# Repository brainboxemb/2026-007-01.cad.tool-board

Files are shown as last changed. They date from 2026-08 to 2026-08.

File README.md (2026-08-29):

# Garage Layout

Parametric OpenSCAD model used as visual support while making layout and construction choices for a private garage / workshop.

> The model and documentation were developed with the assistance of ChatGPT.

## Visual concept

Two visual concept renders are used to explore the intended appearance of the rear-wall tool-board layout. These images are illustrative rather than dimensional; the OpenSCAD model remains the geometric reference.

### Concept — straight view

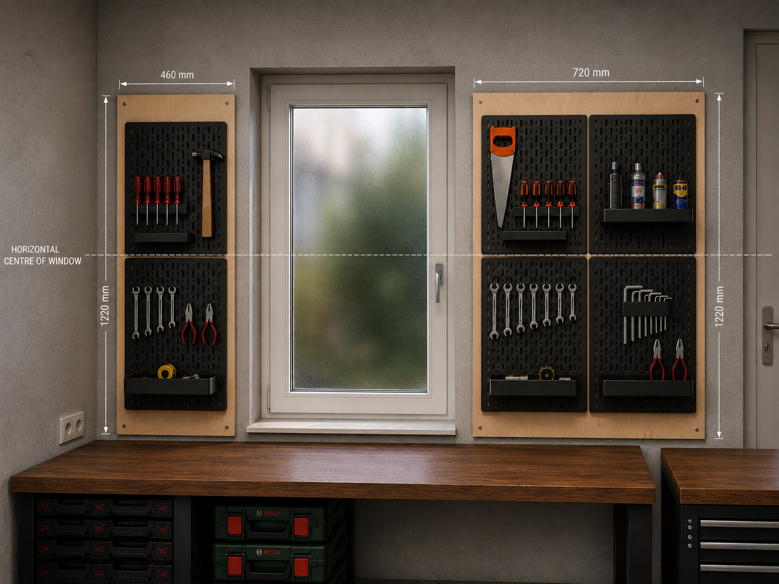
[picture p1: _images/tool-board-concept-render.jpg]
Tool-board concept render — straight


### Concept — angled view

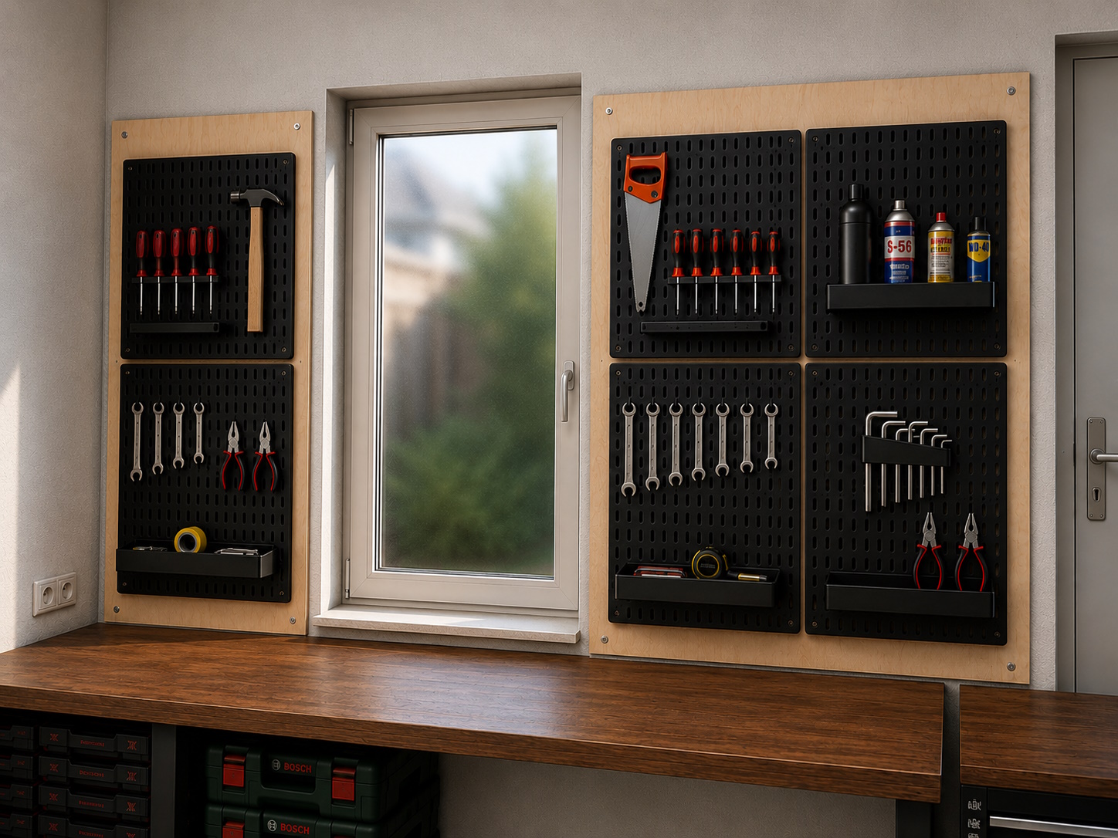
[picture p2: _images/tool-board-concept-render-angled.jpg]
Tool-board concept render — angled


### OpenSCAD implementation — straight view

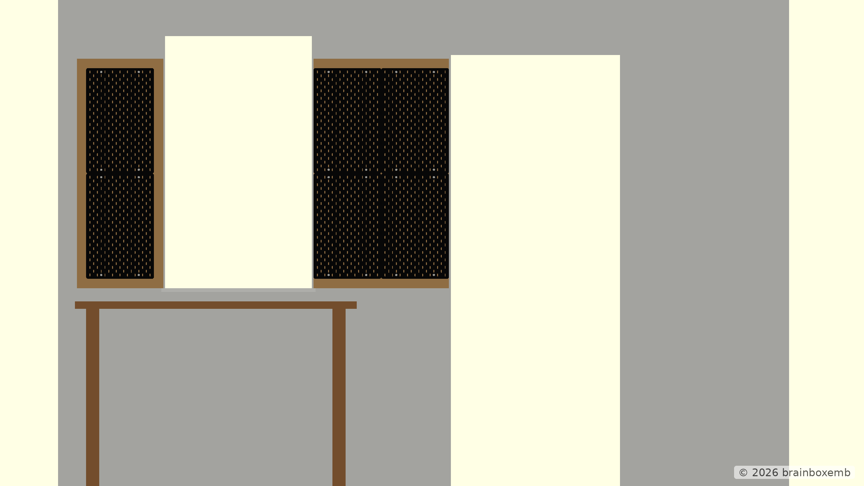
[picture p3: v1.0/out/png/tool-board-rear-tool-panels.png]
OpenSCAD rear tool-board implementation — straight


### OpenSCAD implementation — angled view

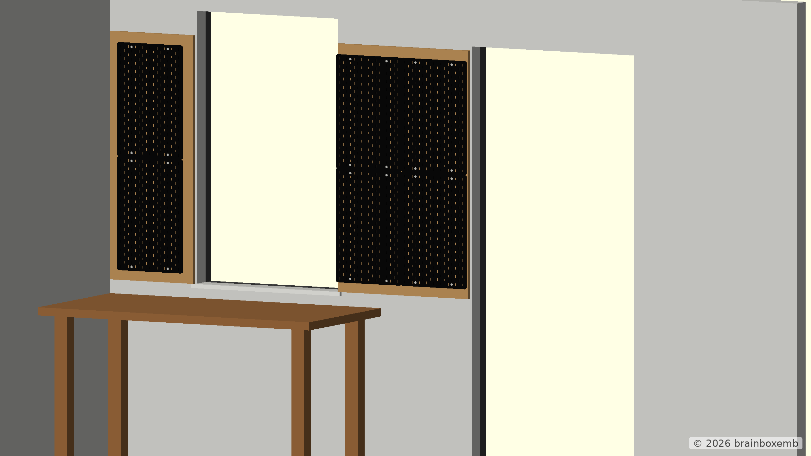
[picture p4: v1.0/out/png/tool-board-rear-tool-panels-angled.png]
OpenSCAD rear tool-board implementation — angled


The concept renders help evaluate visual balance and overall appearance, while the OpenSCAD views are used to check dimensions, alignment and spatial relationships.

For the reference-grid view and additional model notes, see [`v1.0/doc/design-overview.md`](v1.0/doc/design-overview.md).
## Project status

This is primarily a **private design and exploration project**, not an attempt to create a complete architectural or photorealistic garage model.

The main goal is to investigate how OpenSCAD can support practical home and workshop design decisions. The model is used to place real dimensions in context, compare alternatives, check proportions and visualize mounting concepts before buying materials or building anything.

Accuracy is therefore focused on the dimensions and details that affect a decision. Other geometry may deliberately remain simplified.

The current model concentrates on the **rear wall of the garage** and the first wall-storage concept around the existing window, door and workbench.

## Visual design overview

An extended visual overview of the current v1.0 model, including the generated OpenSCAD renders and short notes per view, is available here:

- [v1.0 design overview](v1.0/doc/design-overview.md)

## Rear-wall dimensions

| Item | Dimension |
| --- | ---: |
| Rear wall width | 3800 mm |
| Garage height | 2600 mm |
| Modelled concrete wall thickness | 90 mm |
| Current modelled left-wall depth | 2000 mm (temporary) |
| Window opening | 780 × 1340 mm |
| Window offset from left wall | 480 mm |
| Space above window | 200 mm |
| Door height | 2300 mm |
| Workbench | 1500 × 750 × 990 mm |
| Left backing panel | 460 × 1220 × 18 mm |
| Right backing panel | 720 × 1220 × 18 mm |
| SKÅDIS panel | 360 × 560 mm |

Current SKÅDIS arrangement:

- **left:** 1 × 2 panels;
- **right:** 2 × 2 panels.

## Backing-panel material

The SKÅDIS panels will not be mounted directly to the concrete. A wooden backing panel provides a cleaner mounting surface and makes later changes or additional workshop attachments easier.

Two practical sheet materials were considered.

### 18 mm pine plywood — preferred

The current design uses **18 mm pine plywood**.

Example material:

- GAMMA — Multiplex grenen 244 × 122 cm, 18 mm  
  <https://www.gamma.nl/assortiment/multiplex-grenen-244x122cm-dikte-18mm/p/B368216>

Reasons for preferring plywood:

- cleaner visible finish than OSB;
- good screw holding for SKÅDIS rails and later additions;
- easier to machine accurately for the recessed hanging hardware;
- edges can be finished neatly;
- more appropriate for a visible workshop wall that may evolve over time.

### 18 mm OSB3 — alternative

OSB3 was considered as the lower-cost alternative.

Example material:

- GAMMA — OSB3 244 × 122 cm, 18 mm  
  <https://www.gamma.nl/assortiment/osb3-plaat-244-x-122-cm-18-mm-rechte-kanten/p/B112332>

OSB is structurally suitable for this concept, but the rougher appearance, edges and less refined machining make plywood the preferred option here.

### Cutting concept

The required backing panels are:

- **460 × 1220 × 18 mm** — left;
- **720 × 1220 × 18 mm** — right.

Together they require 1180 mm of the 1220 mm sheet width, so both can be cut from a **single 2440 × 1220 mm sheet** with useful material remaining for tests, spacers or other workshop parts.

## SKÅDIS mounting

The intended pegboards are black IKEA SKÅDIS panels in the standard **36 × 56 cm** orientation.

Product reference:

- IKEA SKÅDIS pegboard 36 × 56 cm  
  <https://www.ikea.com/nl/nl/p/skadis-pegboard-zwart-80534372/>

The SKÅDIS boards are mounted to the plywood using their normal wall-mounting principle. The plywood therefore becomes the structural mounting surface instead of the concrete wall.

Each board is represented as an individual component in OpenSCAD, including rounded corners, the slot pattern and visible mounting points. The model keeps the boards separate rather than treating a 2 × 2 arrangement as one large panel.

## Backing-panel suspension

One design requirement is that the plywood should stay **close to the concrete wall** while preferably remaining removable. This ruled out several otherwise useful mounting methods.

### Options considered

#### Wooden French cleat

A traditional 18 mm plywood French cleat would be simple, strong and easy to make.

It was not selected because it would add approximately another 18 mm behind the already 18 mm backing panel, making the complete wall system unnecessarily deep.

#### STAS French cleat hanger

A thin STAS metal French-cleat system was considered because it keeps the mounting compact and removable.

The stated load ratings of the relatively short STAS hangers did not give enough confidence for a workshop panel that may gradually collect heavier tools.

#### Hettich cabinet hanging rail

Hettich cabinet rails were investigated because the wall rail itself is inexpensive, thin and readily available.

The system is primarily intended to work with dedicated cabinet hangers. It was not clear that the matching components offered a simple flat mounting solution for the back of an 18 mm plywood panel, so the system became more complicated than necessary for this application.

#### Button-fix

Button-fix Type 1 was considered because of its high published load capacity and compact installation.

It was rejected mainly because the required individual mounting points on the concrete wall were less attractive for this design than a clean continuous rail.

#### Concealed Ø35 mm panel hangers

Recessed circular concealed hangers were also considered. They can sit almost completely inside 18 mm sheet material and leave little visible hardware.

They remain an interesting alternative, but require several accurately positioned individual wall anchors and more machining per fixing point.

### Selected concept — ROPRO Heavy Duty Z-bar

The current design uses **ROPRO Heavy Duty French Cleat / Z-bar** profiles.

Selected sets:

- left backing panel: **30 cm set**  
  <https://www.ropro.eu/en/heavy-duty-french-cleat-z-bar-set-30cm.html>
- right backing panel: **60 + 6 cm set**  
  <https://www.ropro.eu/en/heavy-duty-french-cleat-z-bar-set-60-6cm.html>

The reasons for choosing this system are:

- metal construction intended for panel suspension;
- compact wall spacing;
- removable panels;
- continuous wall-side support on the larger panel;
- visually clean wall mounting;
- easy to represent and evaluate in the OpenSCAD model.

ROPRO does not publish one universal kilogram rating for these profiles because the actual capacity depends heavily on the wall, anchors, screws and mounted object. For this garage the concrete wall and final fastener selection therefore remain part of the real-world engineering decision.

### Recessed Z-bar concept

The current OpenSCAD model assumes a **6 mm deep routed recess** in the rear of the 18 mm plywood so the mounting profile can be integrated rather than simply spacing the entire panel away from the wall.

That leaves approximately **12 mm of plywood** at the recessed area. Final screw length, screw type and edge distances therefore still need to be selected carefully before construction.

The long wall rail must also be considered in the recess geometry: the routed area needs to provide clearance for the complete rail when the panel is lowered into position, not just for the short panel-side clips.

Small lower spacers or bumpers may be used to keep the panel parallel to the wall. These are suitable candidates for simple 3D-printed project components.

## Preliminary material list

This is a design-stage list rather than a final purchasing specification.

| Qty. | Item | Current specification / size | Notes |
| ---: | --- | --- | --- |
| 1 | Pine plywood sheet | 2440 × 1220 × 18 mm | Cut both backing panels from one sheet |
| 1 | Left backing panel | 460 × 1220 × 18 mm | Cut from plywood sheet |
| 1 | Right backing panel | 720 × 1220 × 18 mm | Cut from plywood sheet |
| 2 | IKEA SKÅDIS | 360 × 560 mm, black | Left side, stacked vertically |
| 4 | IKEA SKÅDIS | 360 × 560 mm, black | Right side, 2 × 2 |
| 1 | ROPRO Heavy Duty Z-bar set | 300 mm | Left backing panel |
| 1 | ROPRO Heavy Duty Z-bar set | 600 + 60 mm | Right backing panel; one 600 mm wall rail and short panel-side sections |
| TBD | Concrete anchors / screws | suitable for 90 mm concrete wall | Final type depends on wall condition and rail hole geometry |
| TBD | Screws for panel-side Z-bars | suitable for 18 mm plywood with 6 mm recess | Must not penetrate front face |
| TBD | SKÅDIS mounting screws | suitable for 18 mm plywood | Use the IKEA mounting geometry |
| 4 approx. | Lower spacers / bumpers | about 6 mm, final size TBD | Potential 3D-printed parts |

## Render and export naming

Render entry-point filenames do not include the project prefix. The GitHub workflow adds the `tool-board-` prefix to generated render and export output, avoiding duplicated names such as `tool-board-tool-board-...`.

Examples:

```text
garage_rear.scad
rear_tool_panels.scad
tool_panel_mounting_exploded.scad
```

## Repository layout

Each model revision has its own CAD sources and generated output.

```text
.
├── README.md
└── v1.0/
    ├── cad/
    │   ├── main.scad
    │   ├── config.scad
    │   ├── model.md
    │   ├── assemblies/
    │   ├── components/
    │   ├── project_components/
    │   ├── exports/
    │   └── renders/
    ├── out/
    │   ├── png/
    │   └── stl/
    └── doc/
```

### `cad/`

Contains the OpenSCAD source for the version.

- `main.scad` — main interactive entry point and Customizer view;
- `config.scad` — dimensions, visibility switches and project configuration;
- `assemblies/` — larger assemblies composed from project components;
- `components/` — reusable generic components;
- `project_components/` — garage-specific components and placement;
- `exports/` — fixed entry points for geometry export;
- `renders/` — fixed entry points for repeatable PNG renders;
- `model.md` — implementation notes specific to the CAD model.

### `out/`

Generated output:

- `out/png/` — rendered images;
- `out/stl/` — exported printable geometry where applicable.

### `doc/`

Version-specific design documentation that does not belong inside the CAD source tree.

## Using the model

Open:

```text
v1.0/cad/main.scad
```

in OpenSCAD for the normal interactive model.

The Customizer contains switches for major visual elements, including the workbench, floor, rear wall, left wall, plywood backing panels and SKÅDIS system. This makes it possible to simplify the scene while evaluating individual design choices.

The files under `renders/` provide repeatable views, while `exports/` contains geometry-oriented entry points.

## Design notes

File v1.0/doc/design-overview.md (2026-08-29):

# Design overview — v1.0

This document collects the visual views used to evaluate the current tool-board concept for the rear wall of the garage.

The project is primarily a private design study. The OpenSCAD model is used as a dimensional and visual aid for workshop / home-design choices rather than as a photorealistic room-planning model.

## Concept renders

### Straight concept

Tool-board concept render — straight

### Angled concept

Tool-board concept render — angled

These concept renders communicate the intended appearance and composition. They are not authoritative geometry.

## OpenSCAD implementation

### Straight rear-wall view

Rear tool panels

This is the primary dimensional view for checking the relationship between the window, workbench, plywood backing panels and SKÅDIS layout.

### Angled rear-wall view

Rear tool panels — angled

The angled view is taken from inside the garage at approximately standing eye height, looking towards the rear wall. It gives a more natural impression of the tool-board layout and the relationship with the workbench, floor and side wall.

## 100 mm reference-grid view

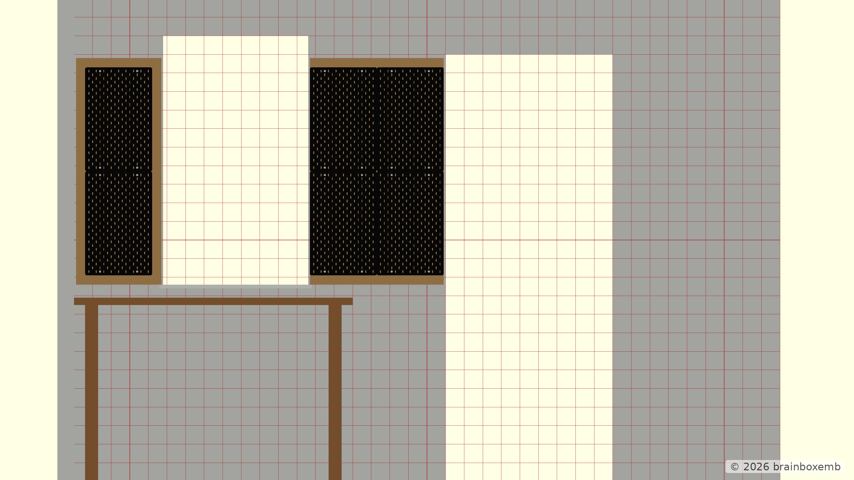
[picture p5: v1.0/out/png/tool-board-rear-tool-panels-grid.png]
Rear tool panels with 100 mm grid


This render adds a 100 mm reference grid across the rear-wall plane. The grid is a visual measuring aid and can also be enabled interactively from the OpenSCAD Customizer.

The plywood backing panels are aligned with the **top of the window sill**. With the current dimensions, the backing panels run from 1060 mm to 2280 mm above floor level.

## SKÅDIS component detail

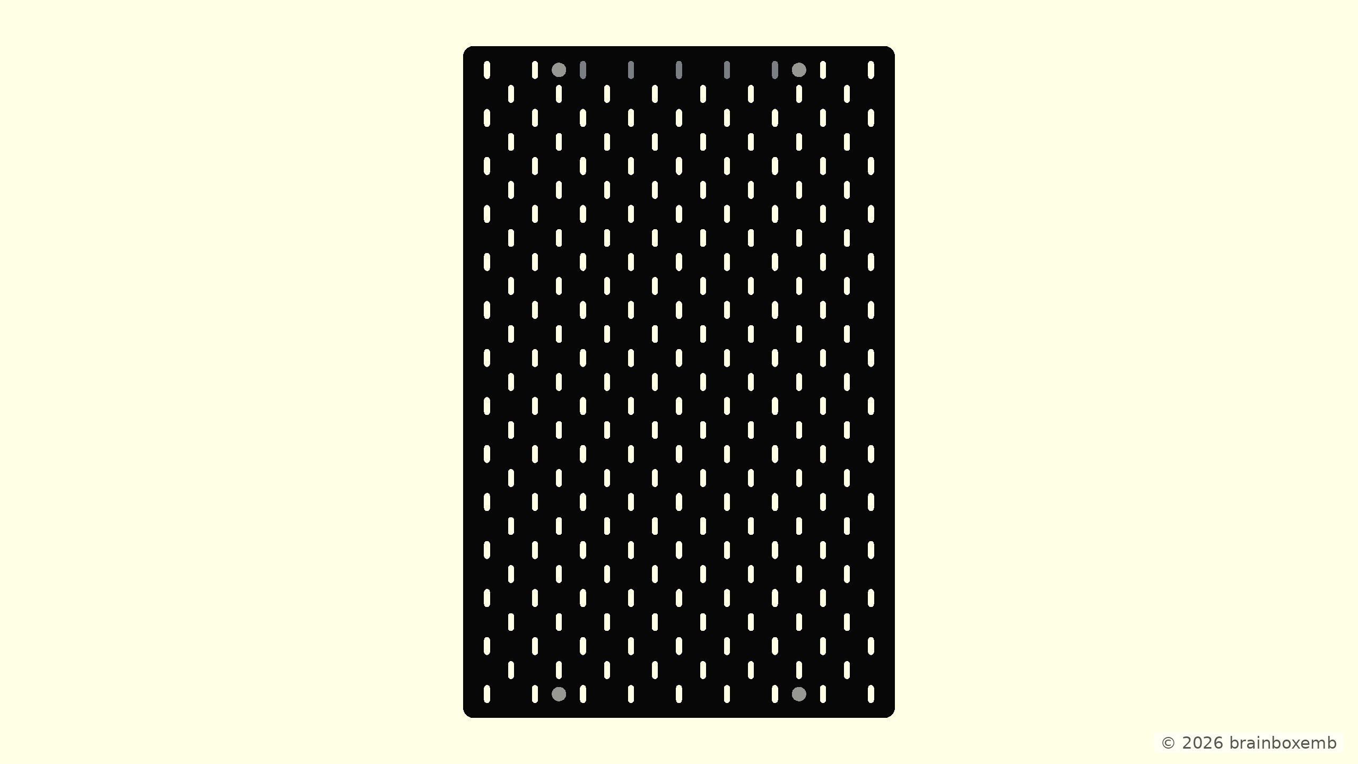
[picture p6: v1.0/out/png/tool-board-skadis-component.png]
SKÅDIS component


This view shows the reusable SKÅDIS component with its rounded corners, slot pattern and visible mounting points.

## Render generation

The images under `v1.0/out/png/` are generated automatically by the repository's GitHub Actions workflow from the OpenSCAD entry points in:

```text
v1.0/cad/renders/
```

The render entry-point files themselves do not contain the `tool-board-` prefix; the build workflow adds that prefix to the generated PNG filenames.

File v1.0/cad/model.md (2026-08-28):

# Garage layout model

Parametric OpenSCAD model for planning the garage layout.

The model and documentation were developed with the assistance of ChatGPT.

## Structure

- `main.scad` — main Customizer entry point.
- `config.scad` — project dimensions and visibility settings.
- `components/` — generic reusable components.
- `project_components/` — garage-specific components or wrappers derived from generic components.
- `assemblies/` — composed garage sections.
- `exports/` — dedicated geometry export entry points.
- `renders/` — dedicated camera/render entry points.

## Current geometry

- Rear wall: 3800 × 2600 mm.
- Concrete wall thickness: 90 mm.
- Window opening: 780 × 1340 mm, 480 mm from the left side and 200 mm below the ceiling.
- Window-to-door spacing: 740 mm.
- Door height: 2300 mm; door width is still provisional at 900 mm.
- Workbench: 1500 × 750 × 990 mm.
- Floor depth is provisional at 2000 mm until the garage depth is measured.

## Rear tool panels

The backing panels use the standard 1220 mm sheet dimension as their height. They are centred vertically relative to the 1340 mm window opening instead of being made as tall as the window.

- Window opening: Z = 1060–2400 mm.
- Backing panels: Z = 1120–2340 mm.
- This leaves 60 mm between each backing-panel edge and the corresponding top/bottom edge of the window opening.
- Two 560 mm SKÅDIS panels occupy 1120 mm vertically, leaving 50 mm of visible wood above and below them.

### Left

- Backing: 460 × 1220 × 18 mm, centred in the 480 mm wall strip left of the window.
- SKÅDIS: 1 × 2 panels of nominal 360 × 560 mm.
- Horizontal wood margin around SKÅDIS: 50 mm per side.
- Ropro mount: Heavy Duty French Cleat Z-Bar 30 cm set (300 mm wall profile + 300 mm counter profile).

### Right

- Backing: 720 × 1220 × 18 mm, centred in the 740 mm wall strip between window and door.
- SKÅDIS: 2 × 2 panels of nominal 360 × 560 mm.
- The two 360 mm panels use the full 720 mm backing width.
- Ropro mount: Heavy Duty French Cleat Z-Bar 60+6 cm set (600 mm wall profile + two 60 mm counter profiles).

## SKÅDIS component

`components/skadis_panel.scad` is now a reusable, recognisable SKÅDIS-style component rather than a plain rectangle.

It includes:

- 360 × 560 mm nominal dimensions;
- rounded outer corners;
- actual cut-out vertical peg slots;
- staggered 40 mm hole grids with a 20 mm offset;
- four visible board mounting points;
- an optional simplified 200 mm upper mounting rail and lower spacers.

IKEA publishes the 36 × 56 cm board size and shows that this size uses the supplied 20 cm wall rail. The exact slot geometry is not dimensioned by IKEA in the assembly document; the model uses the commonly documented SKÅDIS-compatible 5 × 15 mm slot geometry and staggered 40 mm grid for visualization/layout purposes.

## Routed Ropro recess

The Ropro profile is modelled using the published 38 mm profile height and 6 mm wall distance. The exact extrusion cross-section and screw-hole pattern remain intentionally simplified.

A 6 mm deep recess is routed into the back of each multiplex panel over the full length of the wall-side rail. The recess is 1 mm larger around the known 38 mm profile envelope. Routing only below the short counter-profile pieces would not clear the long wall rail.

With 18 mm multiplex, a 6 mm recess leaves 12 mm of material underneath the pocket. The final screw type/length for fixing the counter profile to the multiplex still needs to be checked before treating this as a fabrication-ready detail.

The garage interior is modelled on the negative Y side of the rear wall. The exterior side is positive Y.

## Product references

- Ropro Heavy Duty French Cleat Z-Bar Set 30 cm: https://www.ropro.eu/en/heavy-duty-french-cleat-z-bar-set-30cm.html
- Ropro Heavy Duty French Cleat Z-Bar Set 60+6 cm: https://www.ropro.eu/en/heavy-duty-french-cleat-z-bar-set-60-6cm.html
- IKEA SKÅDIS 36 × 56 cm: https://www.ikea.com/nl/nl/p/skadis-pegboard-zwart-80534372/

## Reference grid

A 100 mm rear-wall reference grid can be enabled with `show_reference_grid` in the Customizer. The grid is a visual aid only and does not affect export geometry.

## Tool-board vertical alignment

The 1220 mm-high multiplex backing panels are aligned with the top of the window sill (`tool_panel_bottom = window_bottom`). With the current dimensions this places them from Z=1060 mm to Z=2280 mm.

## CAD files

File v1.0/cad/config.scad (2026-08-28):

//
// Garage layout - configuration
// Units: millimetres
//

$fn = 48;


/* [View] */

show_rear_wall           = true;
show_left_wall           = true;
show_window_frame        = true;
show_door_frame          = true;
show_window_sill         = true;
show_workbench           = true;
show_floor               = true;
show_tool_backing_panels = true;
show_skadis_panels       = true;
show_tool_panel_mounts   = true;
show_skadis_slot_pattern = true;
show_skadis_mount_points = true;
show_skadis_mount_hardware = false;
show_reference_grid       = false;

/* [Reference grid] */

// Rear-wall dimensional reference grid.
reference_grid_pitch      = 100; // 10 cm
reference_grid_line_width = 2;
reference_grid_depth      = 1;

// Move multiplex + SKADIS towards the garage to inspect the concealed mount.
tool_panel_explode = 0; // [0:5:150]


/* [Garage walls] */

wall_width     = 3800;
wall_height    = 2600;

// Concrete / structural inner shell only.
// Additional exterior wall layers can be added later.
wall_thickness = 90;

// Temporary left-wall depth follows the currently modelled floor depth.
// This will become the measured garage depth later.
left_wall_depth = 2000;


/* [Window opening] */

// Inside view: measured from the left side of the rear wall.
window_left_offset = 480;
window_width       = 780;
window_height      = 1340;
window_top_offset  = 200;

window_bottom = wall_height - window_top_offset - window_height;


/* [Window sill] */

// Projection into the garage from the inside face of the wall.
window_sill_thickness  = 20;
window_sill_depth      = 20;
window_sill_side_extra = 20;


/* [Door opening] */

// Horizontal distance between the right side of the window opening
// and the left side of the door opening.
window_to_door = 740;

// Width is provisional until measured.
door_width  = 900;
door_height = 2300;

door_left = window_left_offset + window_width + window_to_door;


/* [Exterior frames] */

// Simplified visualization. Both frames sit on the exterior side
// of the 90 mm concrete wall.
frame_border = 50;
frame_depth  = 60;


/* [Workbench] */

workbench_width  = 1500;
workbench_depth  = 750;
workbench_height = 990;

workbench_top_thickness = 40;
workbench_leg_size      = 70;
workbench_leg_inset     = 60;

// Inside view: workbench starts at the left end of the rear wall.
workbench_x = 0;


/* [Tool panel backing] */

// Use the 1220 mm sheet dimension directly.
// Align the bottom edge with the TOP of the 20 mm window sill.
// The sill top coincides with the bottom of the window opening.
tool_panel_height = 1220;
tool_panel_bottom = window_bottom;
tool_panel_top    = tool_panel_bottom + tool_panel_height;

tool_panel_thickness = 18;

// Left wall strip is 480 mm; keep 10 mm free on each side.
left_tool_panel_width = 460;
left_tool_panel_x = (window_left_offset - left_tool_panel_width) / 2;

// Right wall strip between window and door is 740 mm; keep 10 mm each side.
right_tool_panel_width = 720;
right_tool_panel_x =
    window_left_offset + window_width
    + (window_to_door - right_tool_panel_width) / 2;


/* [SKADIS] */

skadis_width  = 360;
skadis_height = 560;
skadis_thickness = 5;

// Approximate stand-off created by the original IKEA wall rail/spacers.
skadis_mount_gap = 15;

// Geometry used for the recognisable SKADIS pattern.
skadis_corner_radius = 9;
skadis_slot_width    = 5;
skadis_slot_height   = 15;
skadis_grid_pitch    = 40;
skadis_grid_offset   = 20;

// The 36 cm board uses the supplied 20 cm wall rail. The four visible board
// fasteners are modelled at the corresponding left/right positions.
skadis_rail_length = 200;
skadis_mount_point_z_inset = 20;
skadis_mount_head_diameter = 12;
skadis_mount_head_depth = 2;


/* [Tool panel mounting - Ropro] */

// Ropro Heavy Duty French Cleat / Z-bar known dimensions.
cleat_profile_height = 38;
cleat_wall_distance  = 6;

// Route the full wall-rail envelope into the back of the 18 mm multiplex.
// This leaves 12 mm of multiplex below the recess and must be considered
// when selecting screws for the panel-side counter profile.
cleat_recess_depth = 6;
cleat_recess_clearance = 1;

// Position rail near the upper edge, safely above the panel centre of gravity.
cleat_top_inset = 50;

// Left panel: Ropro Heavy Duty 30 cm set (300 + 300 mm).
left_cleat_wall_length  = 300;
left_cleat_panel_length = 300;

// Right panel: Ropro Heavy Duty 60+6 cm set:
// 600 mm wall rail + two 60 mm panel-side counter profiles.
right_cleat_wall_length = 600;
right_cleat_panel_piece_length = 60;


/* [Floor] */

// Temporary depth until the complete garage depth is measured.
floor_depth     = 2000;
floor_thickness = 100;

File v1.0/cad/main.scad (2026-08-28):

//
// Garage layout - main model
//

include <config.scad>
include <assemblies/garage_rear.scad>

garage_rear_scene(
    rear_wall_visible     = show_rear_wall,
    left_wall_visible     = show_left_wall,
    window_frame_visible  = show_window_frame,
    door_frame_visible    = show_door_frame,
    window_sill_visible   = show_window_sill,
    workbench_visible     = show_workbench,
    floor_visible         = show_floor,
    tool_backing_visible  = show_tool_backing_panels,
    skadis_visible        = show_skadis_panels,
    tool_mounts_visible   = show_tool_panel_mounts,
    skadis_slots_visible  = show_skadis_slot_pattern,
    skadis_mount_points_visible = show_skadis_mount_points,
    skadis_mount_hardware_visible = show_skadis_mount_hardware,
    reference_grid_visible = show_reference_grid,
    reference_grid_pitch_value = reference_grid_pitch,
    reference_grid_line_width_value = reference_grid_line_width,
    reference_grid_depth_value = reference_grid_depth,
    tool_panels_explode   = tool_panel_explode
);

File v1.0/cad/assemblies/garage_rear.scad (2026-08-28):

//
// Assembly: current rear section of the garage.
// Expects config.scad to be included by the calling file.
//

include <../project_components/rear_wall.scad>
include <../project_components/left_wall.scad>
include <../project_components/rear_window.scad>
include <../project_components/rear_door.scad>
include <../project_components/garage_workbench.scad>
include <../project_components/garage_floor.scad>
include <../project_components/rear_tool_panels.scad>
include <../components/reference_grid.scad>

module garage_rear_scene(
    rear_wall_visible     = true,
    left_wall_visible     = true,
    window_frame_visible  = true,
    door_frame_visible    = true,
    window_sill_visible   = true,
    workbench_visible     = true,
    floor_visible         = true,
    tool_backing_visible  = true,
    skadis_visible        = true,
    tool_mounts_visible   = true,
    skadis_slots_visible  = true,
    skadis_mount_points_visible = true,
    skadis_mount_hardware_visible = false,
    reference_grid_visible = false,
    reference_grid_pitch_value = 100,
    reference_grid_line_width_value = 2,
    reference_grid_depth_value = 1,
    tool_panels_explode   = 0
) {
    if (floor_visible)
        color([0.68, 0.68, 0.68])
            garage_floor(
                width     = wall_width,
                depth     = floor_depth,
                thickness = floor_thickness
            );

    if (rear_wall_visible)
        color([0.82, 0.82, 0.80])
            rear_wall(
                width         = wall_width,
                height        = wall_height,
                thickness     = wall_thickness,
                window_x      = window_left_offset,
                window_z      = window_bottom,
                window_width  = window_width,
                window_height = window_height,
                door_x        = door_left,
                door_width    = door_width,
                door_height   = door_height
            );

    if (reference_grid_visible)
        color([0.85, 0.15, 0.15, 0.45])
            reference_grid_xz(
                width      = wall_width,
                height     = wall_height,
                pitch      = reference_grid_pitch_value,
                line_width = reference_grid_line_width_value,
                depth      = reference_grid_depth_value,
                y          = -1.5
            );

    if (left_wall_visible)
        color([0.82, 0.82, 0.80])
            left_wall(
                depth     = left_wall_depth,
                height    = wall_height,
                thickness = wall_thickness
            );

    if (window_frame_visible)
        color([0.25, 0.25, 0.25])
            rear_window_frame(
                x              = window_left_offset,
                z              = window_bottom,
                wall_thickness = wall_thickness,
                opening_width  = window_width,
                opening_height = window_height,
                frame_border   = frame_border,
                frame_depth    = frame_depth
            );

    if (door_frame_visible)
        color([0.25, 0.25, 0.25])
            rear_door_frame(
                x              = door_left,
                wall_thickness = wall_thickness,
                opening_width  = door_width,
                opening_height = door_height,
                frame_border   = frame_border,
                frame_depth    = frame_depth
            );

    if (window_sill_visible)
        color([0.88, 0.88, 0.86])
            rear_window_sill(
                x             = window_left_offset,
                z             = window_bottom,
                opening_width = window_width,
                thickness     = window_sill_thickness,
                depth         = window_sill_depth,
                side_extra    = window_sill_side_extra
            );

    if (workbench_visible)
        color([0.58, 0.39, 0.22])
            garage_workbench(
                x             = workbench_x,
                width         = workbench_width,
                depth         = workbench_depth,
                height        = workbench_height,
                top_thickness = workbench_top_thickness,
                leg_size      = workbench_leg_size,
                leg_inset     = workbench_leg_inset
            );

    if (tool_backing_visible || skadis_visible || tool_mounts_visible)
        rear_tool_panels(
            backing_visible = tool_backing_visible,
            skadis_visible  = skadis_visible,
            mounting_visible = tool_mounts_visible,
            slot_pattern    = skadis_slots_visible,
            skadis_mount_points_visible = skadis_mount_points_visible,
            skadis_mount_hardware_visible = skadis_mount_hardware_visible,
            explode         = tool_panels_explode
        );

}

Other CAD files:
v1.0/cad/components/backing_panel.scad
v1.0/cad/components/floor_slab.scad
v1.0/cad/components/french_cleat_zbar.scad
v1.0/cad/components/opening_frame.scad
v1.0/cad/components/reference_grid.scad
v1.0/cad/components/skadis_panel.scad
v1.0/cad/components/workbench.scad
v1.0/cad/exports/left_tool_backing_panel.scad
v1.0/cad/exports/right_tool_backing_panel.scad
v1.0/cad/project_components/garage_floor.scad
v1.0/cad/project_components/garage_workbench.scad
v1.0/cad/project_components/left_wall.scad
v1.0/cad/project_components/rear_door.scad
v1.0/cad/project_components/rear_tool_panels.scad
v1.0/cad/project_components/rear_wall.scad
v1.0/cad/project_components/rear_window.scad
v1.0/cad/renders/rear_tool_panels.scad
v1.0/cad/renders/rear_tool_panels_angled.scad
v1.0/cad/renders/rear_tool_panels_grid.scad
v1.0/cad/renders/skadis_component.scad

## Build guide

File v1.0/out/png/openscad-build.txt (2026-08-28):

Generated with: OpenSCAD version 2026.08.28
Requested version: latest
Resolved snapshot: 2026.08.28
Latest refresh policy: 30 day(s)

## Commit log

2026-08-28 initial version
    [backing_panel.scad, config.scad, floor_slab.scad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]
2026-08-28 Update OpenSCAD generated outputs
    [tool-board-left-tool-backing-panel.stl, tool-board-rear-wall.stl, tool-board-right-tool-backing-panel.stl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]
2026-08-29 update image
    [rear_tool_panels_angled.scad, tool-board-left-tool-backing-panel.stl, tool-board-right-tool-backing-panel.stl]
